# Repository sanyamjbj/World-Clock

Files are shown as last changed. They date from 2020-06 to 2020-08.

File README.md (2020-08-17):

# World_Clock_8085
An Intel 8085 microprocessor based device displaying the time of all the geographical time zones based on a user input.<br/>

Main_code.asm --------> The 8085 assembly language program.<br/>
Peripheral.brd -------> Board layout file for the I/O board. <br/>
Peripheral.sch -------> Circuit Schematic file for I/O board. <br/>
CPU.brd --------------> Board layout file for the 8085 CPU board. <br/>
world_clock_2.0.sch --> Circuit Schematic file for the 8085 CPU board. <br/>
All board and schematic files are made using Autodesk EAGLE. <br/>

[Image (a) of the Device](https://drive.google.com/file/d/1ZphsaR_vkj9hESxW5N7R6vfBDCEByzWG/view?usp=sharing)
Image of the Device

[Image (b) of the Device](https://drive.google.com/file/d/1xtrZFzuJcVHUMF8EjI57J5fJ46bng3HB/view?usp=sharing)
Image (b) of the Device

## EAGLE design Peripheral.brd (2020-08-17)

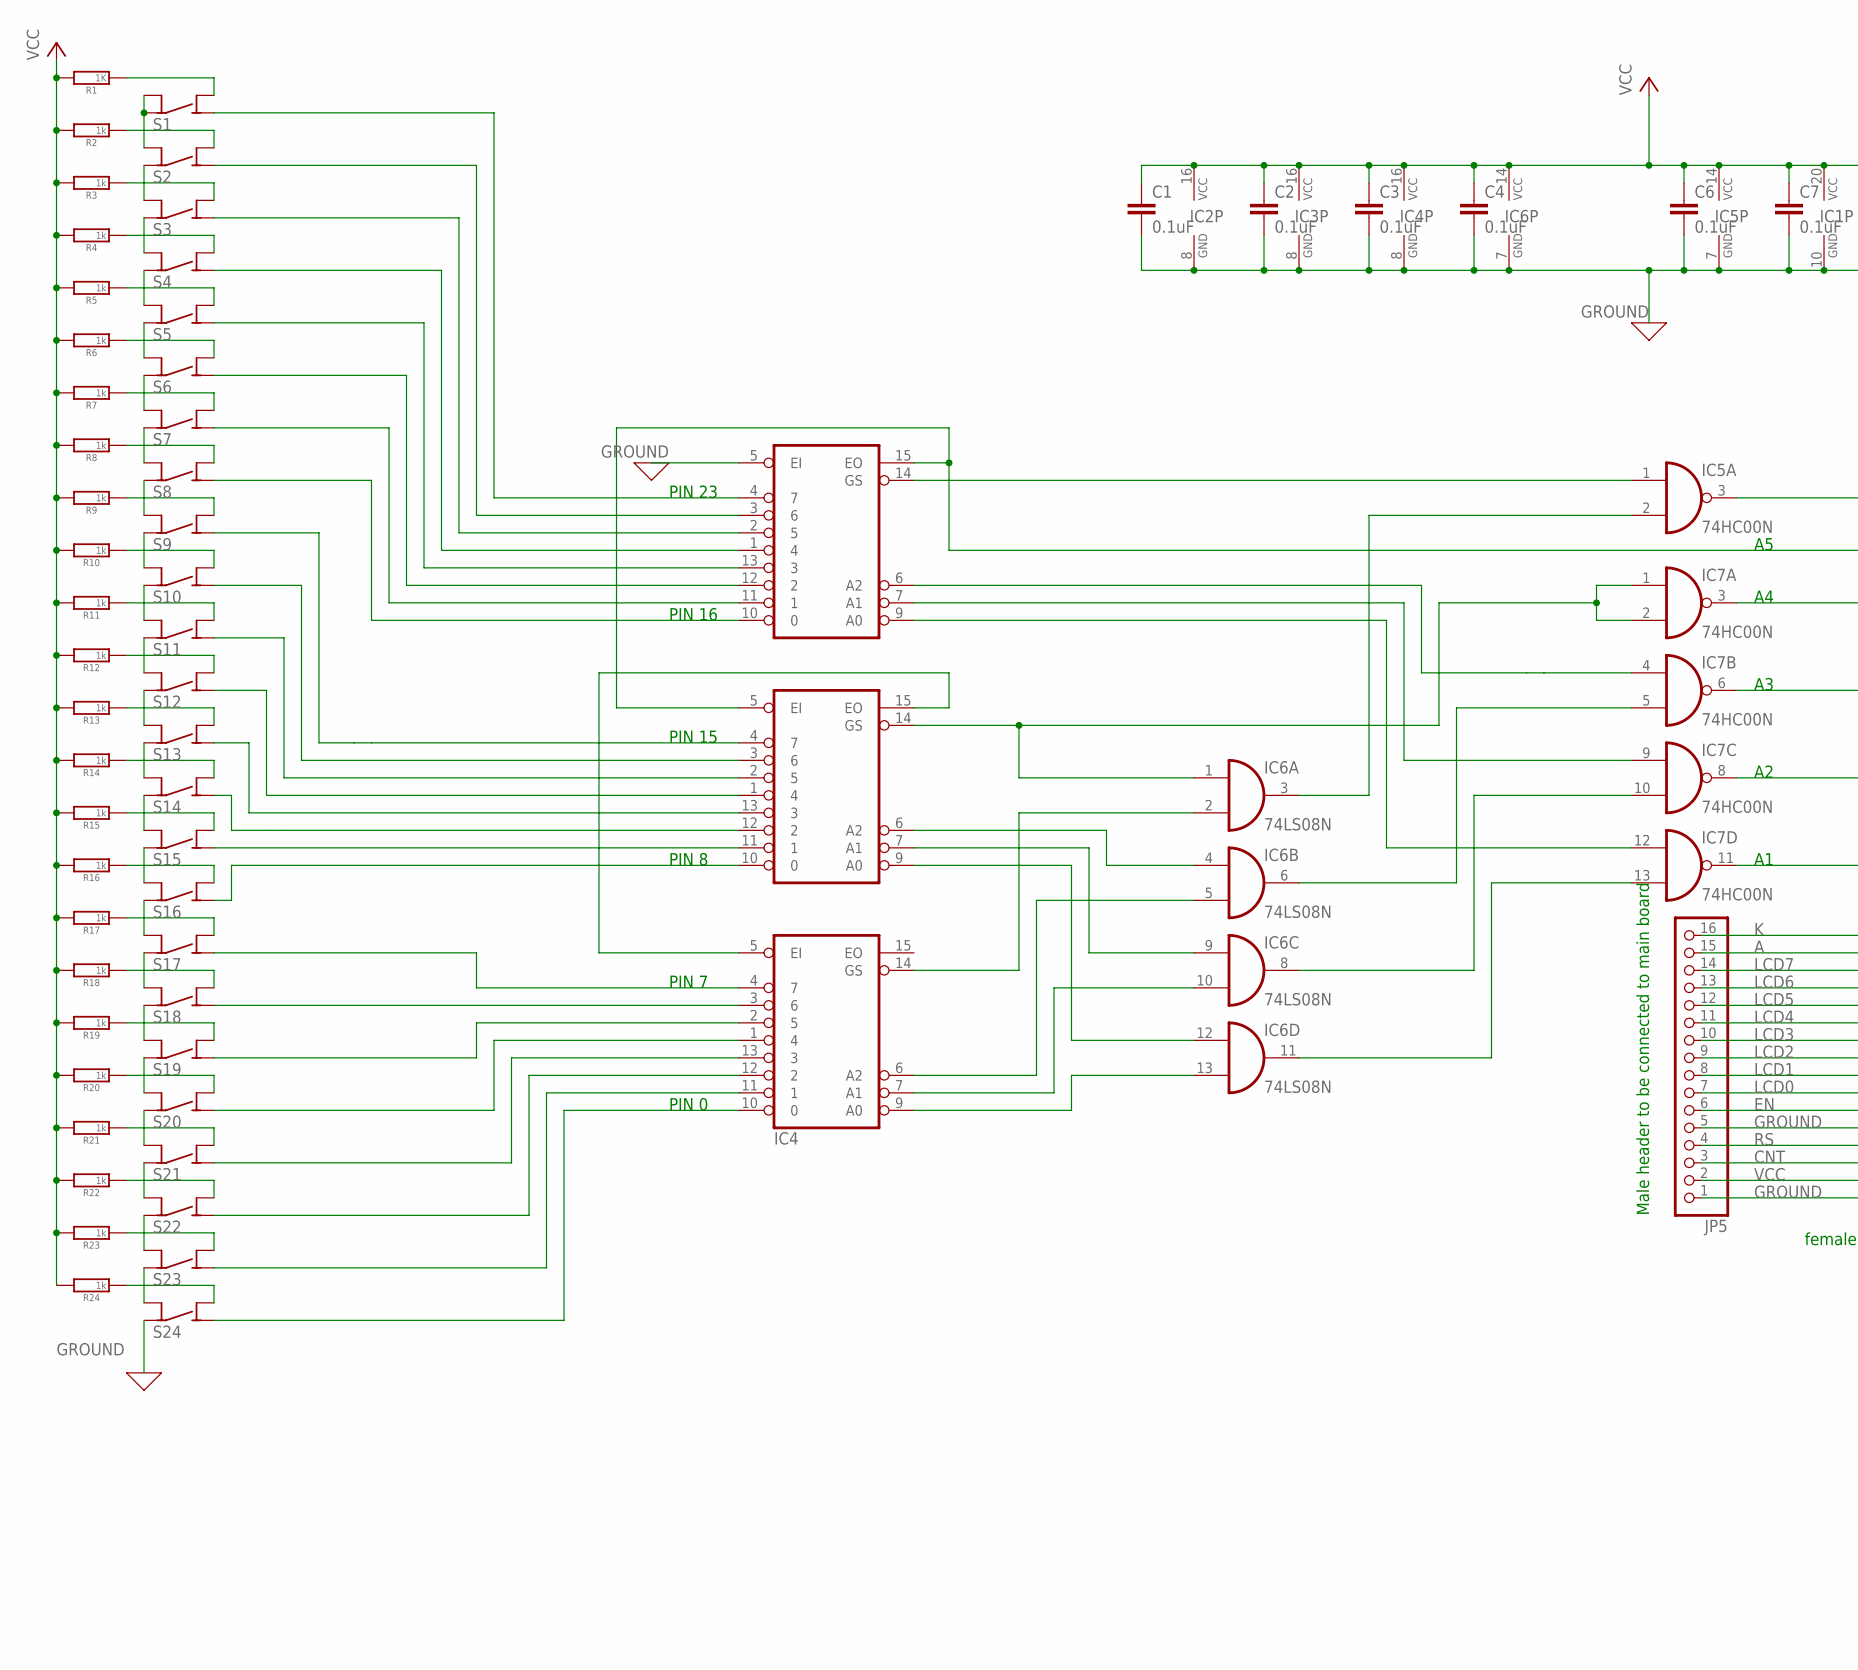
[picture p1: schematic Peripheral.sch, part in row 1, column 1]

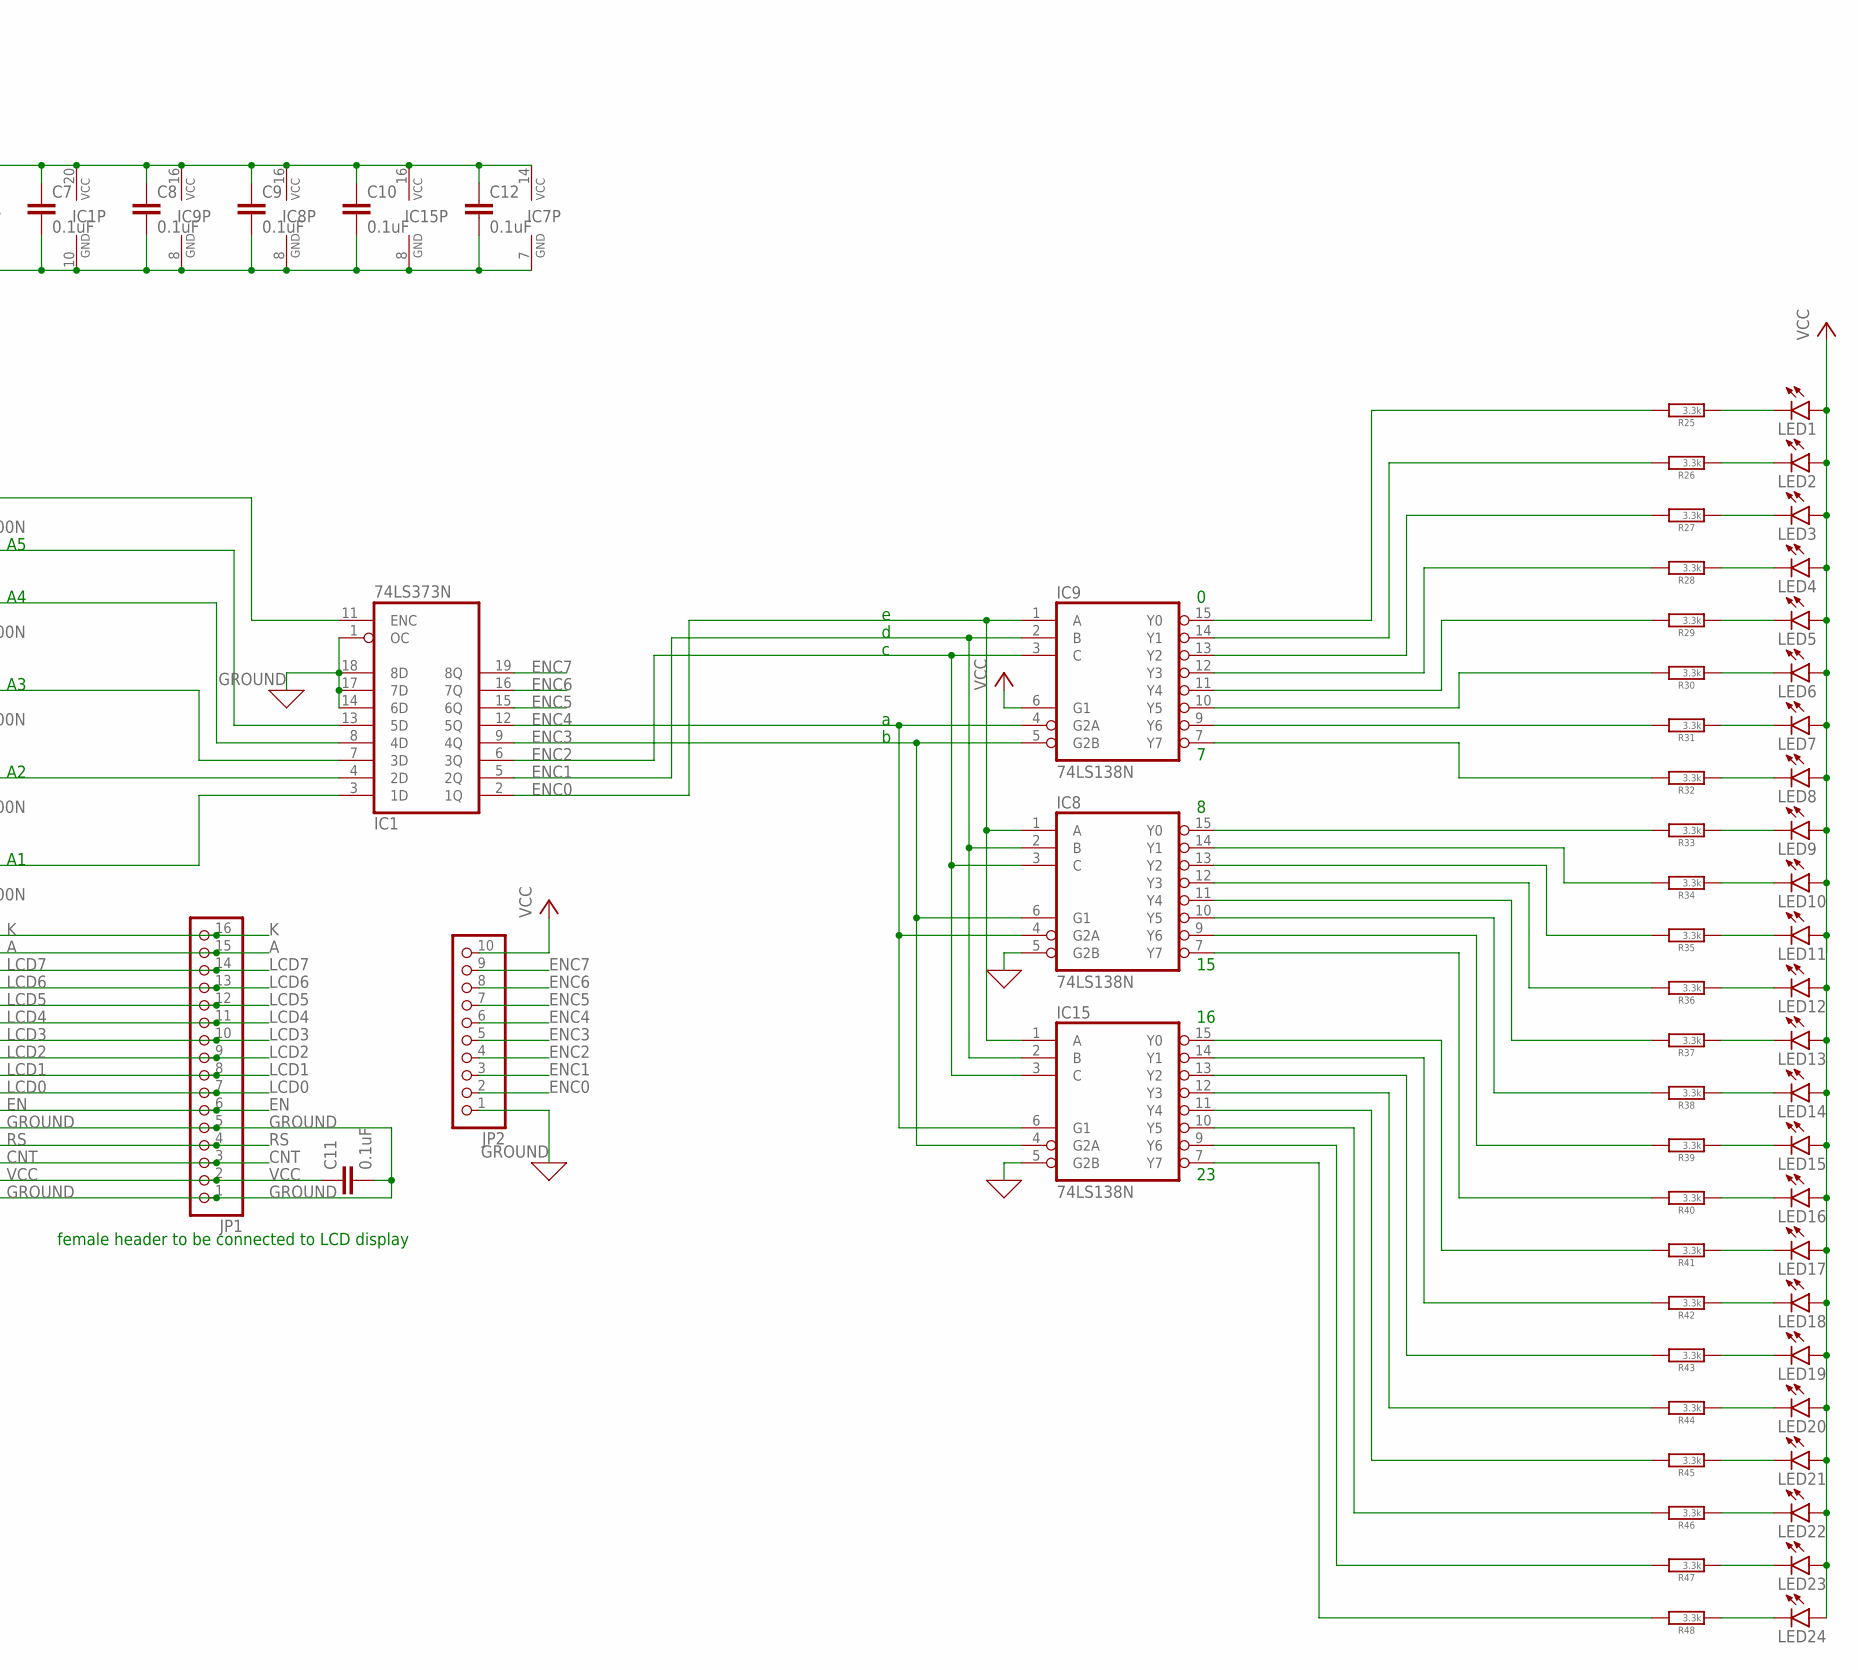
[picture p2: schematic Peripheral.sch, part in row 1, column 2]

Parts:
C1, C2, C3, C4, C6, C7, C8, C9, C10, C12: 0.1uF; C2.5-2
C11: 0.1uF; C025-025X050
IC1: 74LS373N; DIL20
IC2, IC3, IC4: 74HC148N; DIL16
IC5, IC7: 74HC00N; DIL14
IC6: 74LS08N; DIL14
IC8, IC9, IC15: 74LS138N; DIL16
JP1, JP5: PINHD-1X16; 1X16
JP2: PINHD-1X10; 1X10
LED1, LED2, LED3, LED4, LED5, LED6, LED7, LED8, LED9, LED10, LED11, LED12, LED13, LED14, LED15, LED16, LED17, LED18, LED19, LED20, LED21, LED22, LED23, LED24: LED5MM
R1: 1K; 1/6W(5MM)
R2, R3, R4, R5, R6, R7, R8, R9, R10, R11, R12, R13, R14, R15, R16, R17, R18, R19, R20, R21, R22, R23, R24: 1k; 1/6W(5MM)
R25, R26, R27, R28, R29, R30, R31, R32, R33, R34, R35, R36, R37, R38, R39, R40, R41, R42, R43, R44, R45, R46, R47, R48: 3.3k; 1/6W(5MM)
S1, S2, S3, S4, S5, S6, S7, S8, S9, S10, S11, S12, S13, S14, S15, S16, S17, S18, S19, S20, S21, S22, S23, S24: SPST4B3F-10XX; B3F-10XX

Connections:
A: JP1.15, JP5.15
CNT: JP1.3, JP5.3
EN: JP1.6, JP5.6
ENC0: IC1.2 (1Q), IC8.1 (A), IC9.1 (A), IC15.1 (A), JP2.2
ENC1: IC1.5 (2Q), IC8.2 (B), IC9.2 (B), IC15.2 (B), JP2.3
ENC2: IC1.6 (3Q), IC8.3 (C), IC9.3 (C), IC15.3 (C), JP2.4
ENC3: IC1.9 (4Q), IC8.6 (G1), IC9.5 (G2B), IC15.4 (G2A), JP2.5
ENC4: IC1.12 (5Q), IC8.4 (G2A), IC9.4 (G2A), IC15.6 (G1), JP2.6
ENC5: IC1.15 (6Q), JP2.7
ENC6: IC1.16 (7Q), JP2.8
ENC7: IC1.19 (8Q), JP2.9
GROUND: C1.2, C2.2, C3.2, C4.2, C6.2, C7.2, C8.2, C9.2, C10.2, C11.2, C12.2, IC1.1 (OC), IC1.10 (GND), IC1.14 (6D), IC1.17 (7D), IC1.18 (8D), IC2.5 (EI), IC2.8 (GND), IC3.8 (GND), IC4.8 (GND), IC5.7 (GND), IC6.7 (GND), IC7.7 (GND), IC8.5 (G2B), IC8.8 (GND), IC9.8 (GND), IC15.5 (G2B), IC15.8 (GND), JP1.1, JP1.5, JP2.1, JP5.1, JP5.5, S1.COM@1 (COM), S1.COM@2 (COM), S2.COM@1 (COM), S2.COM@2 (COM), S3.COM@1 (COM), S3.COM@2 (COM), S4.COM@1 (COM), S4.COM@2 (COM), S5.COM@1 (COM), S5.COM@2 (COM), S6.COM@1 (COM), S6.COM@2 (COM), S7.COM@1 (COM), S7.COM@2 (COM), S8.COM@1 (COM), S8.COM@2 (COM), S9.COM@1 (COM), S9.COM@2 (COM), S10.COM@1 (COM), S10.COM@2 (COM), S11.COM@1 (COM), S11.COM@2 (COM), S12.COM@1 (COM), S12.COM@2 (COM), S13.COM@1 (COM), S13.COM@2 (COM), S14.COM@1 (COM), S14.COM@2 (COM), S15.COM@1 (COM), S15.COM@2 (COM), S16.COM@1 (COM), S16.COM@2 (COM), S17.COM@1 (COM), S17.COM@2 (COM), S18.COM@1 (COM), S18.COM@2 (COM), S19.COM@1 (COM), S19.COM@2 (COM), S20.COM@1 (COM), S20.COM@2 (COM), S21.COM@1 (COM), S21.COM@2 (COM), S22.COM@1 (COM), S22.COM@2 (COM), S23.COM@1 (COM), S23.COM@2 (COM), S24.COM@1 (COM), S24.COM@2 (COM)
K: JP1.16, JP5.16
LCD0: JP1.7, JP5.7
LCD1: JP1.8, JP5.8
LCD2: JP1.9, JP5.9
LCD3: JP1.10, JP5.10
LCD4: JP1.11, JP5.11
LCD5: JP1.12, JP5.12
LCD6: JP1.13, JP5.13
LCD7: JP1.14, JP5.14
unnamed: IC2.10 (0), S8.NO@1 (NO)
unnamed: IC3.15 (EO), IC4.5 (EI)
unnamed: IC2.11 (1), S7.NO@1 (NO)
unnamed: IC2.9 (A0), IC7.12 (I0)
unnamed: IC2.12 (2), S6.NO@1 (NO)
unnamed: IC2.7 (A1), IC7.9 (I0)
unnamed: IC2.13 (3), S5.NO@1 (NO)
unnamed: IC2.1 (4), S4.NO@1 (NO)
unnamed: IC3.9 (A0), IC6.12 (I0)
unnamed: IC4.9 (A0), IC6.13 (I1)
unnamed: IC3.7 (A1), IC6.9 (I0)
unnamed: IC4.7 (A1), IC6.10 (I1)
unnamed: IC3.6 (A2), IC6.4 (I0)
unnamed: IC4.6 (A2), IC6.5 (I1)
unnamed: IC2.2 (5), S3.NO@1 (NO)
unnamed: IC6.11 (O), IC7.13 (I1)
unnamed: IC2.3 (6), S2.NO@1 (NO)
unnamed: IC6.8 (O), IC7.10 (I1)
unnamed: IC2.6 (A2), IC7.4 (I0)
unnamed: IC6.6 (O), IC7.5 (I1)
unnamed: IC4.4 (7), S17.NO@1 (NO)
unnamed: IC3.14 (GS), IC6.1 (I0), IC7.1 (I0), IC7.2 (I1)
unnamed: R1.1, S1.NO@2 (NO)
unnamed: R2.1, S2.NO@2 (NO)
unnamed: R3.1, S3.NO@2 (NO)
unnamed: R4.1, S4.NO@2 (NO)
unnamed: R5.1, S5.NO@2 (NO)
unnamed: R6.1, S6.NO@2 (NO)
unnamed: R7.1, S7.NO@2 (NO)
unnamed: R8.1, S8.NO@2 (NO)
unnamed: R9.1, S9.NO@2 (NO)
unnamed: R10.1, S10.NO@2 (NO)
unnamed: R11.1, S11.NO@2 (NO)
unnamed: R12.1, S12.NO@2 (NO)
unnamed: R13.1, S13.NO@2 (NO)
unnamed: R14.1, S14.NO@2 (NO)
unnamed: R15.1, S15.NO@2 (NO)
unnamed: R16.1, S16.NO@2 (NO)
unnamed: R17.1, S17.NO@2 (NO)
unnamed: R18.1, S18.NO@2 (NO)
unnamed: R19.1, S19.NO@2 (NO)
unnamed: R20.1, S20.NO@2 (NO)
unnamed: R21.1, S21.NO@2 (NO)
unnamed: R22.1, S22.NO@2 (NO)
unnamed: R23.1, S23.NO@2 (NO)
unnamed: R24.1, S24.NO@2 (NO)
unnamed: IC1.3 (1D), IC7.11 (O)
unnamed: IC1.4 (2D), IC7.8 (O)
unnamed: IC4.2 (5), S19.NO@1 (NO)
unnamed: IC4.1 (4), S20.NO@1 (NO)
unnamed: IC4.13 (3), S21.NO@1 (NO)
unnamed: IC4.12 (2), S22.NO@1 (NO)
unnamed: IC4.11 (1), S23.NO@1 (NO)
unnamed: IC4.10 (0), S24.NO@1 (NO)
unnamed: IC4.3 (6), S18.NO@1 (NO)
unnamed: IC1.7 (3D), IC7.6 (O)
unnamed: IC1.8 (4D), IC7.3 (O)
unnamed: IC4.14 (GS), IC6.2 (I1)
unnamed: IC2.14 (GS), IC5.1 (I0)
unnamed: IC2.4 (7), S1.NO@1 (NO)
unnamed: IC5.2 (I1), IC6.3 (O)
unnamed: IC3.4 (7), S9.NO@1 (NO)
unnamed: IC3.10 (0), S16.NO@1 (NO)
unnamed: IC3.11 (1), S15.NO@1 (NO)
unnamed: IC3.12 (2), S14.NO@1 (NO)
unnamed: IC3.13 (3), S13.NO@1 (NO)
unnamed: IC3.1 (4), S12.NO@1 (NO)
unnamed: IC3.2 (5), S11.NO@1 (NO)
unnamed: IC3.3 (6), S10.NO@1 (NO)
unnamed: IC1.11 (ENC), IC5.3 (O)
unnamed: IC1.13 (5D), IC2.15 (EO), IC3.5 (EI)
unnamed: IC9.15 (Y0), R25.2
unnamed: LED1.K (C), R25.1
unnamed: IC9.14 (Y1), R26.2
unnamed: IC9.13 (Y2), R27.2
unnamed: IC9.12 (Y3), R28.2
unnamed: IC9.11 (Y4), R29.2
unnamed: IC9.10 (Y5), R30.2
unnamed: IC9.9 (Y6), R31.2
unnamed: IC9.7 (Y7), R32.2
unnamed: IC8.15 (Y0), R33.2
unnamed: IC8.14 (Y1), R34.2
unnamed: IC8.13 (Y2), R35.2
unnamed: IC8.12 (Y3), R36.2
unnamed: IC8.11 (Y4), R37.2
unnamed: IC8.10 (Y5), R38.2
unnamed: IC8.9 (Y6), R39.2
unnamed: IC8.7 (Y7), R40.2
unnamed: IC15.15 (Y0), R41.2
unnamed: IC15.14 (Y1), R42.2
unnamed: IC15.13 (Y2), R43.2
unnamed: IC15.12 (Y3), R44.2
unnamed: IC15.11 (Y4), R45.2
unnamed: IC15.10 (Y5), R46.2
unnamed: IC15.9 (Y6), R47.2
unnamed: IC15.7 (Y7), R48.2
unnamed: LED2.K (C), R26.1
unnamed: LED3.K (C), R27.1
unnamed: LED4.K (C), R28.1
unnamed: LED5.K (C), R29.1
unnamed: LED6.K (C), R30.1
unnamed: LED7.K (C), R31.1
unnamed: LED8.K (C), R32.1
unnamed: LED9.K (C), R33.1
unnamed: LED10.K (C), R34.1
unnamed: LED11.K (C), R35.1
unnamed: LED12.K (C), R36.1
unnamed: LED13.K (C), R37.1
unnamed: LED14.K (C), R38.1
unnamed: LED15.K (C), R39.1
unnamed: LED16.K (C), R40.1
unnamed: LED17.K (C), R41.1
unnamed: LED18.K (C), R42.1
unnamed: LED19.K (C), R43.1
unnamed: LED20.K (C), R44.1
unnamed: LED21.K (C), R45.1
unnamed: LED22.K (C), R46.1
unnamed: LED23.K (C), R47.1
unnamed: LED24.K (C), R48.1
RS: JP1.4, JP5.4
VCC: C1.1, C2.1, C3.1, C4.1, C6.1, C7.1, C8.1, C9.1, C10.1, C11.1, C12.1, IC1.20 (VCC), IC2.16 (VCC), IC3.16 (VCC), IC4.16 (VCC), IC5.14 (VCC), IC6.14 (VCC), IC7.14 (VCC), IC8.16 (VCC), IC9.6 (G1), IC9.16 (VCC), IC15.16 (VCC), JP1.2, JP2.10, JP5.2, LED1.A, LED2.A, LED3.A, LED4.A, LED5.A, LED6.A, LED7.A, LED8.A, LED9.A, LED10.A, LED11.A, LED12.A, LED13.A, LED14.A, LED15.A, LED16.A, LED17.A, LED18.A, LED19.A, LED20.A, LED21.A, LED22.A, LED23.A, LED24.A, R1.2, R2.2, R3.2, R4.2, R5.2, R6.2, R7.2, R8.2, R9.2, R10.2, R11.2, R12.2, R13.2, R14.2, R15.2, R16.2, R17.2, R18.2, R19.2, R20.2, R21.2, R22.2, R23.2, R24.2

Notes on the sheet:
PIN 16
PIN 23
PIN 15
PIN 8
PIN 7
PIN 0
Male header to be connected to main board
female header to be connected to LCD display

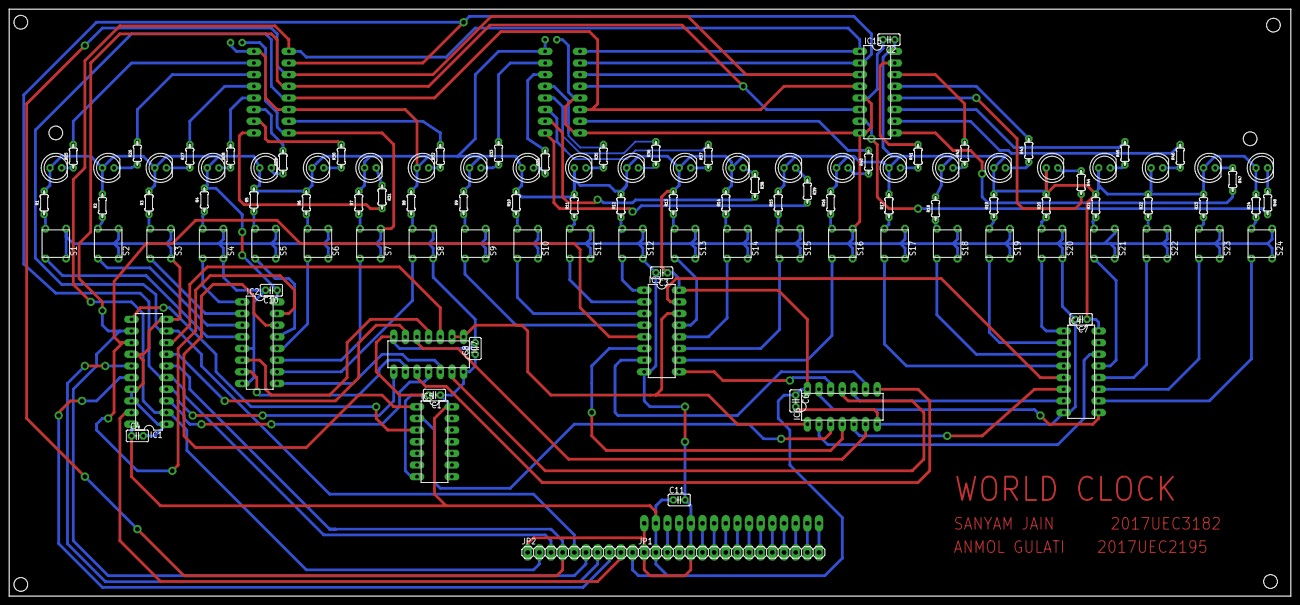
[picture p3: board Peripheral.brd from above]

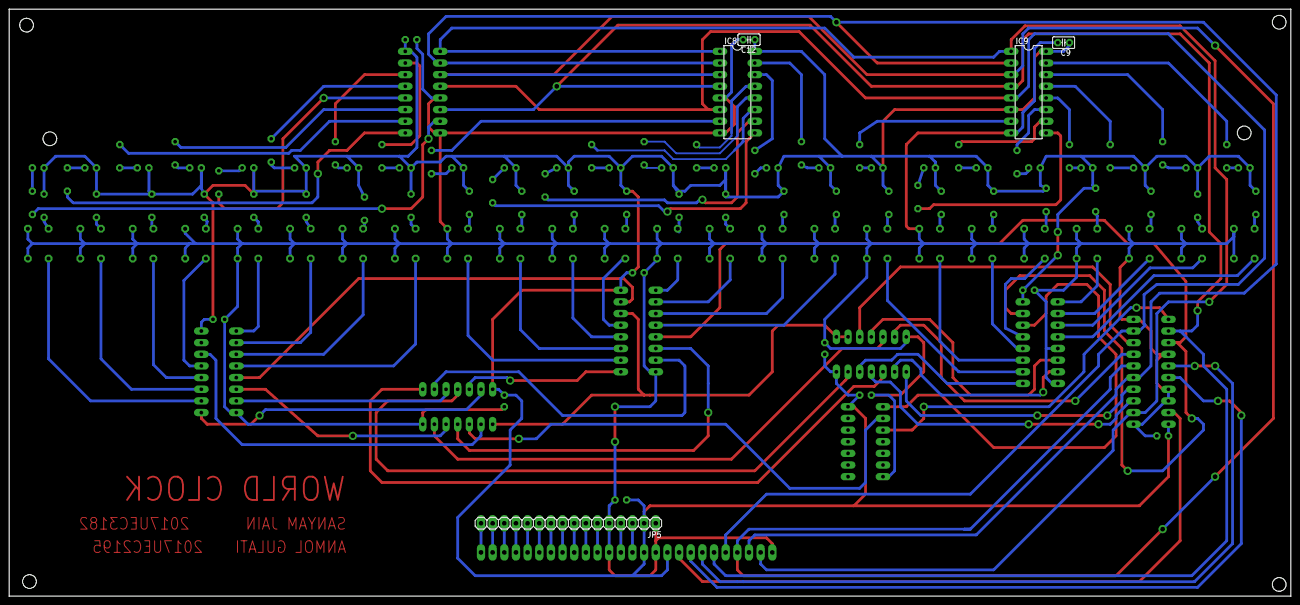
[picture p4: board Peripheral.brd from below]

Board: 2 copper layers, 279.4 x 127.9 mm, 120 parts (5 on the bottom side), 142 nets.

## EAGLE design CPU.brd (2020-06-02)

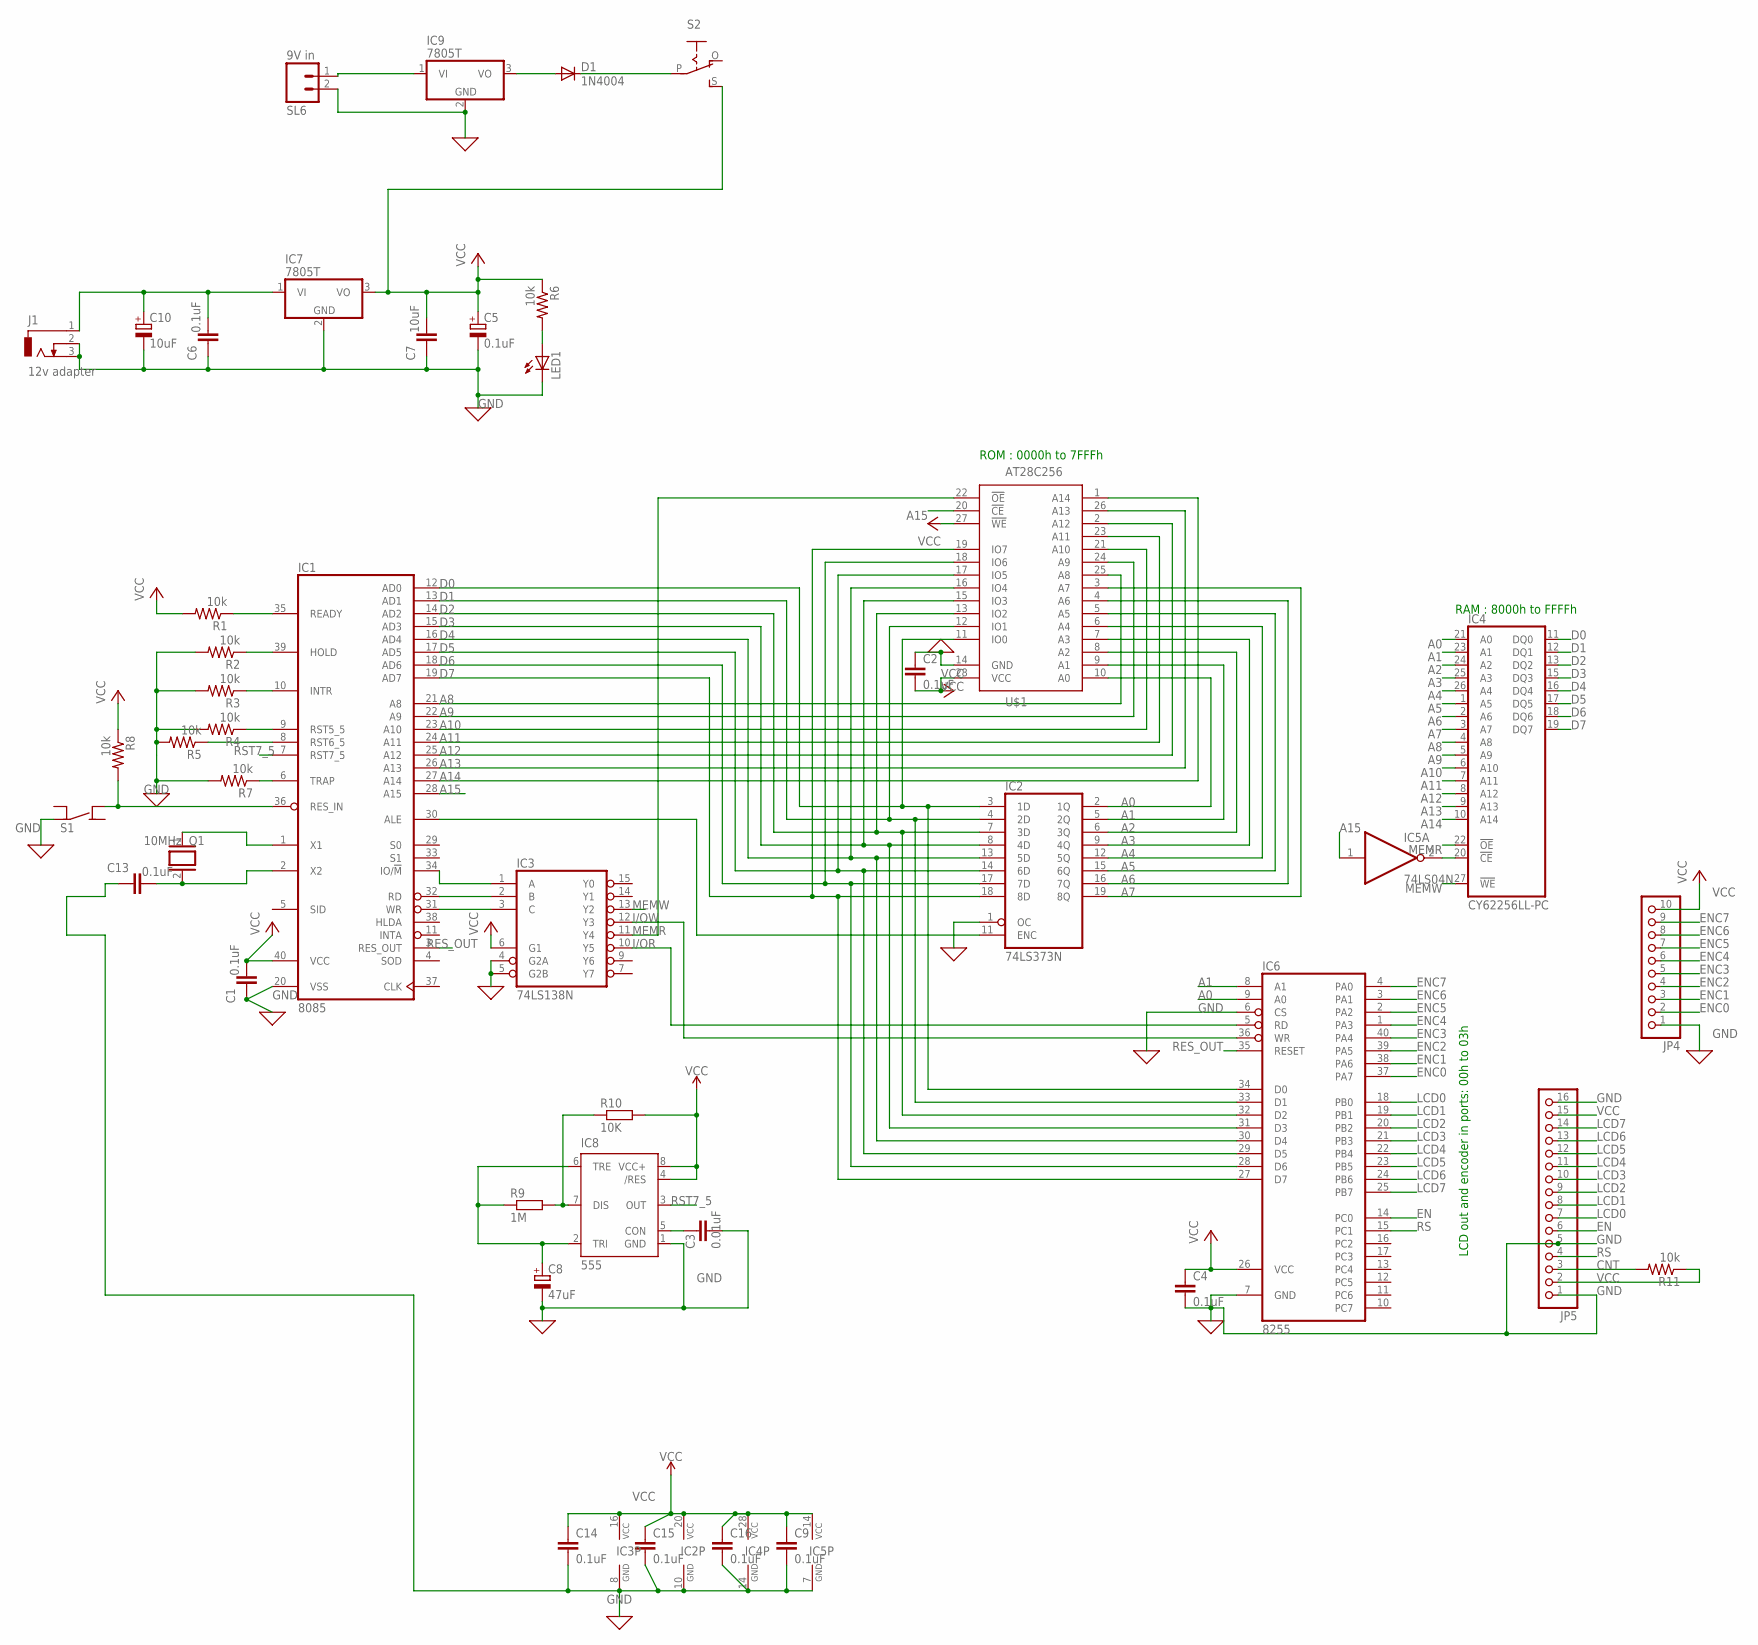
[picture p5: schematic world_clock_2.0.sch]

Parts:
C1, C2, C4, C6, C9, C13, C14, C15, C16: 0.1uF; C025-024X044
C3: 0.01uF; C2.5-2
C5: 0.1uF; E5-8,5
C7: 10uF; C025-024X044
C8: 47uF; E5-8,5
C10: 10uF; E5-8,5
D1: 1N4004; DO41-10
IC1: 8085; DIL40
IC2: 74LS373N; DIL20
IC3: 74LS138N; DIL16
IC4: CY62256LL-PC; DIL28-6
IC5: 74LS04N; DIL14
IC6: 8255; DIL40
IC7, IC9: 7805T; TO220H
IC8: 555; DIP08-KIT
J1: 12v adapter; DCJ0303
JP4: PINHD-1X10; 1X10
JP5: PINHD-1X16; 1X16
LED1: LED5MM
Q1: 10MHz; QS
R1, R2, R3, R4, R5, R6, R7, R8, R11: 10k; 0207/7
R9: 1M; 0204/5
R10: 10K; 0204/5
S1: SPST4B3F-10XX; B3F-10XX
S2: EG1218S; EG1218
SL6: 9V in; 02P
U$1: AT28C256; DIL28-6

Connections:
A0: IC2.2 (1Q), IC4.21 (A0), IC6.9 (A0), U$1.10 (A0)
A1: IC2.5 (2Q), IC4.23 (A1), IC6.8 (A1), U$1.9 (A1)
A2: IC2.6 (3Q), IC4.24 (A2), U$1.8 (A2)
A3: IC2.9 (4Q), IC4.25 (A3), U$1.7 (A3)
A4: IC2.12 (5Q), IC4.26 (A4), U$1.6 (A4)
A5: IC2.15 (6Q), IC4.1 (A5), U$1.5 (A5)
A6: IC2.16 (7Q), IC4.2 (A6), U$1.4 (A6)
A7: IC2.19 (8Q), IC4.3 (A7), U$1.3 (A7)
A8: IC1.21 (A8), IC4.4 (A8), U$1.25 (A8)
A9: IC1.22 (A9), IC4.5 (A9), U$1.24 (A9)
A10: IC1.23 (A10), IC4.6 (A10), U$1.21 (A10)
A11: IC1.24 (A11), IC4.7 (A11), U$1.23 (A11)
A12: IC1.25 (A12), IC4.8 (A12), U$1.2 (A12)
A13: IC1.26 (A13), IC4.9 (A13), U$1.26 (A13)
A14: IC1.27 (A14), IC4.10 (A14), U$1.1 (A14)
A15: IC1.28 (A15), IC5.1 (I), U$1.20 (!CE)
CNT: JP5.3, R11.2
D0: IC1.12 (AD0), IC2.3 (1D), IC4.11 (DQ0), IC6.34 (D0), U$1.11 (IO0)
D1: IC1.13 (AD1), IC2.4 (2D), IC4.12 (DQ1), IC6.33 (D1), U$1.12 (IO1)
D2: IC1.14 (AD2), IC2.7 (3D), IC4.13 (DQ2), IC6.32 (D2), U$1.13 (IO2)
D3: IC1.15 (AD3), IC2.8 (4D), IC4.15 (DQ3), IC6.31 (D3), U$1.15 (IO3)
D4: IC1.16 (AD4), IC2.13 (5D), IC4.16 (DQ4), IC6.30 (D4), U$1.16 (IO4)
D5: IC1.17 (AD5), IC2.14 (6D), IC4.17 (DQ5), IC6.29 (D5), U$1.17 (IO5)
D6: IC1.18 (AD6), IC2.17 (7D), IC4.18 (DQ6), IC6.28 (D6), U$1.18 (IO6)
D7: IC1.19 (AD7), IC2.18 (8D), IC4.19 (DQ7), IC6.27 (D7), U$1.19 (IO7)
EN: IC6.14 (PC0), JP5.6
ENC0: IC6.37 (PA7), JP4.2
ENC1: IC6.38 (PA6), JP4.3
ENC2: IC6.39 (PA5), JP4.4
ENC3: IC6.40 (PA4), JP4.5
ENC4: IC6.1 (PA3), JP4.6
ENC5: IC6.2 (PA2), JP4.7
ENC6: IC6.3 (PA1), JP4.8
ENC7: IC6.4 (PA0), JP4.9
GND: C1.1, C2.1, C3.2, C4.2, C5.-, C6.1, C7.1, C8.-, C9.2, C10.-, C13.1, C14.2, C15.2, C16.2, IC1.20 (VSS), IC2.1 (OC), IC2.10 (GND), IC3.4 (G2A), IC3.5 (G2B), IC3.8 (GND), IC4.14 (GND), IC5.7 (GND), IC6.6 (CS), IC6.7 (GND), IC7.2 (GND), IC8.1 (GND), IC9.2 (GND), J1.2, J1.3, JP4.1, JP5.1, JP5.5, JP5.16, LED1.K (C), R2.2, R3.2, R4.2, R5.2, R7.2, S1.COM@1 (COM), SL6.2, U$1.14 (GND)
I/OR: IC3.10 (Y5), IC6.5 (RD)
I/OW: IC3.12 (Y3), IC6.36 (WR)
LCD0: IC6.18 (PB0), JP5.7
LCD1: IC6.19 (PB1), JP5.8
LCD2: IC6.20 (PB2), JP5.9
LCD3: IC6.21 (PB3), JP5.10
LCD4: IC6.22 (PB4), JP5.11
LCD5: IC6.23 (PB5), JP5.12
LCD6: IC6.24 (PB6), JP5.13
LCD7: IC6.25 (PB7), JP5.14
MEMR: IC3.11 (Y4), IC4.22 (!OE), U$1.22 (!OE)
MEMW: IC3.13 (Y2), IC4.27 (!WE)
unnamed: C8.+, IC8.2 (TRI), IC8.6 (TRE), R9.1
unnamed: C6.2, C10.+, IC7.1 (VI), J1.1
unnamed: IC1.1 (X1), Q1.1
unnamed: C13.2, IC1.2 (X2), Q1.2
unnamed: IC1.35 (READY), R1.1
unnamed: IC1.39 (HOLD), R2.1
unnamed: IC8.7 (DIS), R9.2, R10.1
unnamed: IC1.10 (INTR), R3.1
unnamed: IC1.30 (ALE), IC2.11 (ENC)
unnamed: IC1.9 (RST5_5), R4.1
unnamed: IC1.8 (RST6_5), R5.1
unnamed: C3.1, IC8.5 (CON)
unnamed: IC1.6 (TRAP), R7.1
unnamed: IC9.1 (VI), SL6.1
unnamed: IC1.36 (RES_IN), R8.2, S1.NO@2 (NO)
unnamed: D1.A, IC9.3 (VO)
unnamed: D1.C, S2.P
unnamed: LED1.A, R6.2
unnamed: IC4.20 (!CE), IC5.2 (O)
unnamed: IC1.34 (IO/!M), IC3.1 (A)
unnamed: IC1.32 (RD), IC3.2 (B)
unnamed: IC1.31 (WR), IC3.3 (C)
RES_OUT: IC1.3 (RES_OUT), IC6.35 (RESET)
RS: IC6.15 (PC1), JP5.4
RST7_5: IC1.7 (RST7_5), IC8.3 (OUT)
VCC: C1.2, C2.2, C4.1, C5.+, C7.2, C9.1, C14.1, C15.1, C16.1, IC1.40 (VCC), IC2.20 (VCC), IC3.6 (G1), IC3.16 (VCC), IC4.28 (VCC), IC5.14 (VCC), IC6.26 (VCC), IC7.3 (VO), IC8.4 (/RES), IC8.8 (VCC+), JP4.10, JP5.2, JP5.15, R1.2, R6.1, R8.1, R10.2, R11.1, S2.S, U$1.27 (!WE), U$1.28 (VCC)

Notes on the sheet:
ROM : 0000h to 7FFFh
RAM : 8000h to FFFFh
LCD out and encoder in ports: 00h to 03h

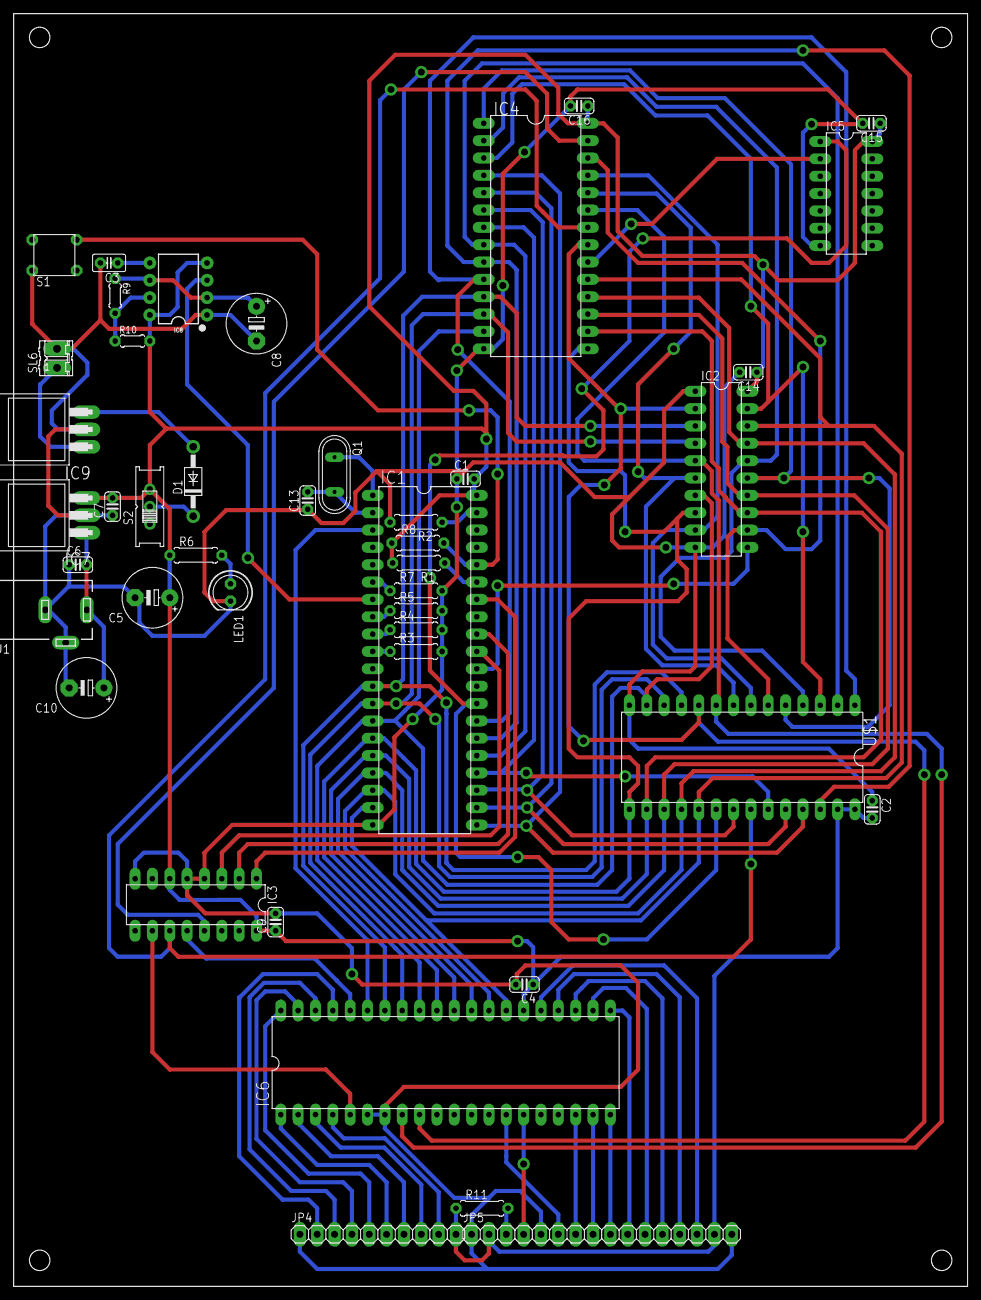
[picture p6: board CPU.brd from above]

Board: 2 copper layers, 139.7 x 186.4 mm, 44 parts (0 on the bottom side), 73 nets.

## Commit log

2020-08-17 8085 Assembly Code
2020-08-17 Board File for the Peripheral I/O PCB
    [Peripheral.brd]
2020-08-17 Schematic for the Peripheral I/O PCB
    [Peripheral.sch]
2020-08-17 Board file for the 8085 CPU PCB
    [CPU.brd]

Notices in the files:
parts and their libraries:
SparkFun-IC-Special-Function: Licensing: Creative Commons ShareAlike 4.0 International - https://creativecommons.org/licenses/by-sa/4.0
